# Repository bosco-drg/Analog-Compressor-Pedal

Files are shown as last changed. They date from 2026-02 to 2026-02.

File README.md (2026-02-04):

# Guitar Pedal — Analog Compressor

> Complete analog guitar compressor pedal project, including schematic and PCB design (KiCad) and simulations (LTSpice).

---

## Quick overview

This project designs and documents an **analog guitar compressor**: input/output adaptation, amplification, envelope detection, and gain control. It includes the **schematic**, **PCB**, as well as **simulations** and **test results**.

### Key features

- **Analog compression**: dynamic reduction of the audio signal
- **Complete signal chain**: input adaptation, amplification, peak detection, gain control, output adaptation
- **Hardware design**: schematic + PCB routing in KiCad
- **Simulation**: LTSpice models and sub‑block tests
- **Visual documentation**: block diagrams and simulation captures

---

## Circuit overview

<div align="center">

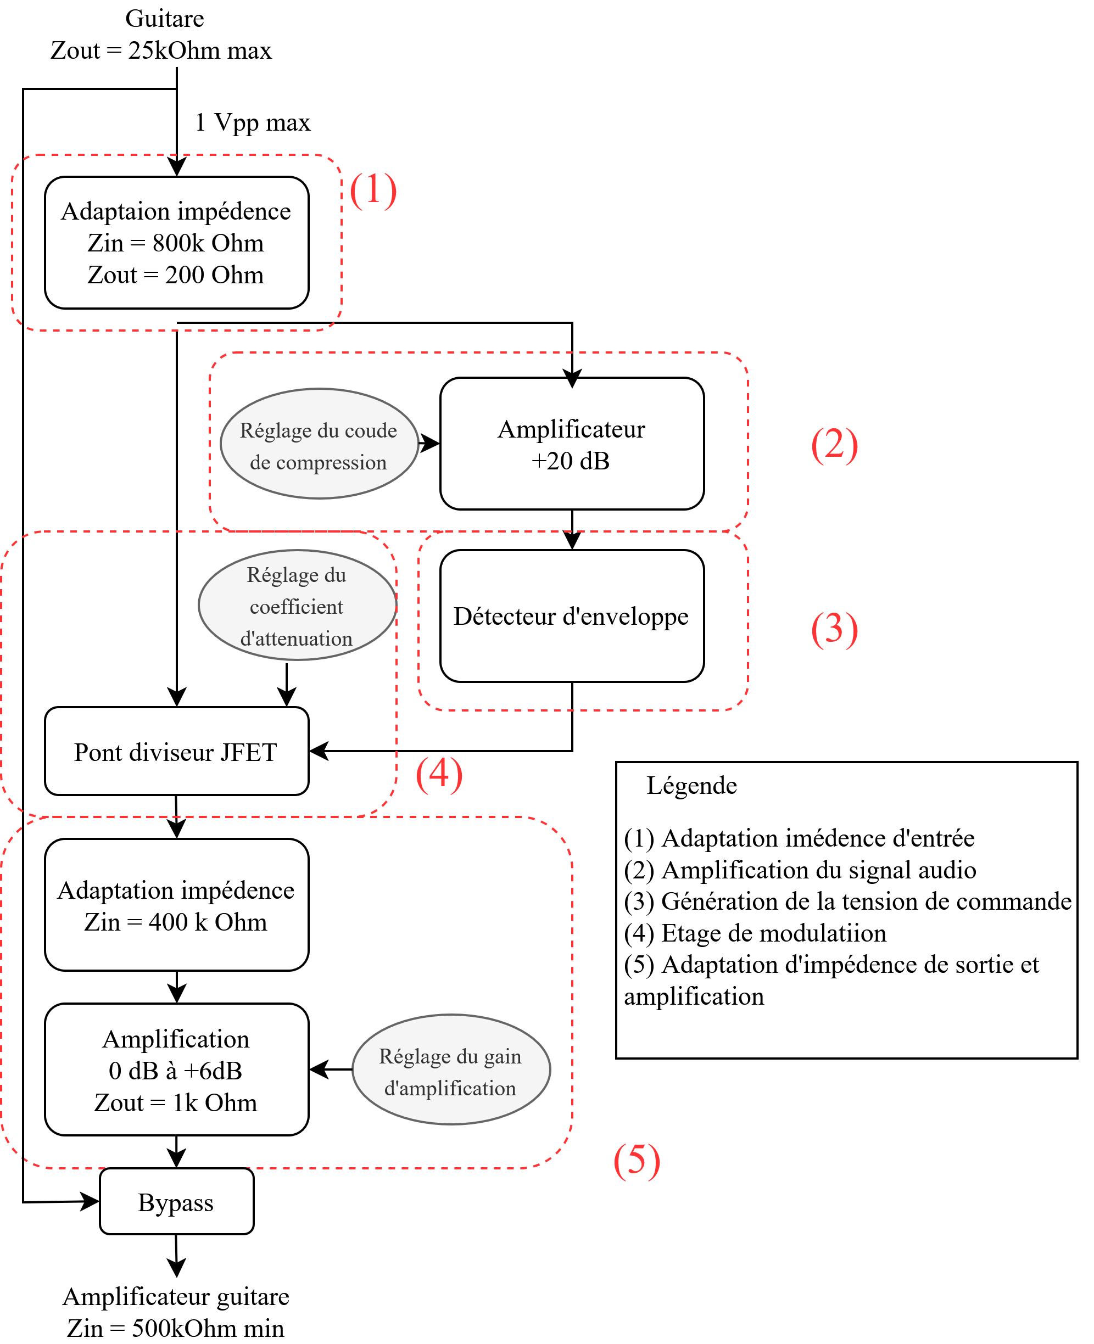
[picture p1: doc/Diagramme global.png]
Global diagram


**Global diagram** — *Functional architecture of the pedal*

</div>

<div align="center">

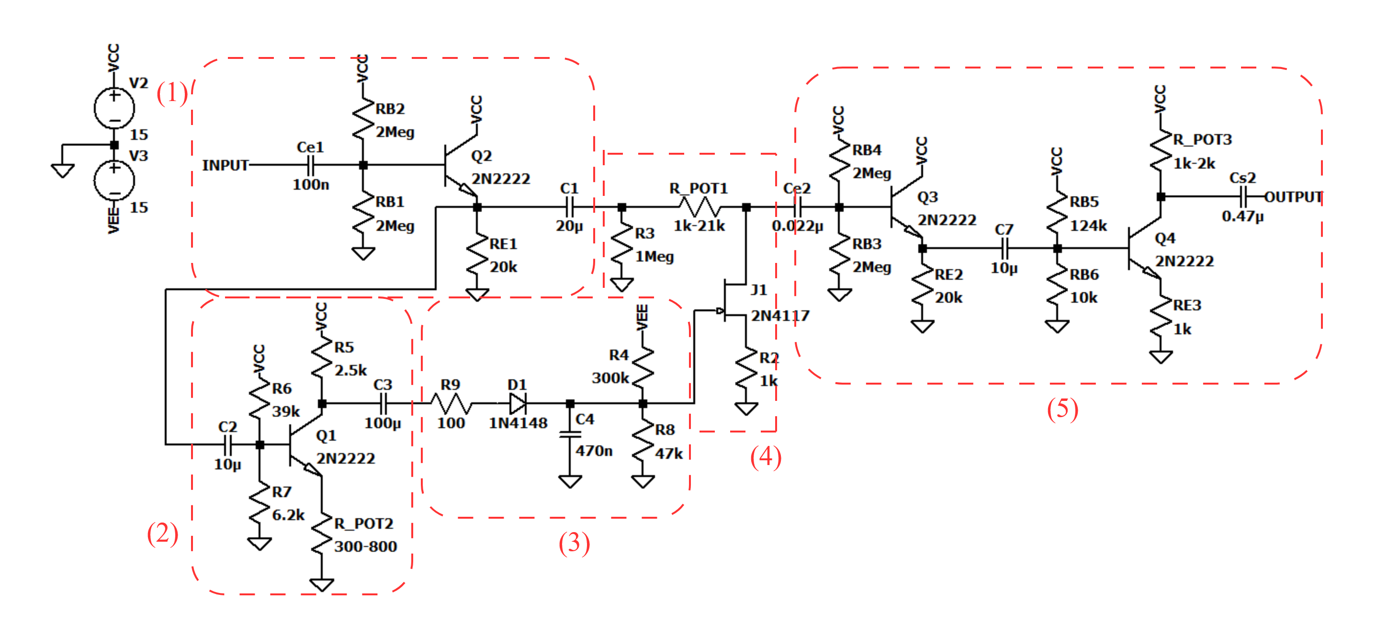
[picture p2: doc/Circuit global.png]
Global circuit


**Global circuit** — *Schematic overview*

</div>

---

## Sub‑block details

### Input adaptation

<div align="center">

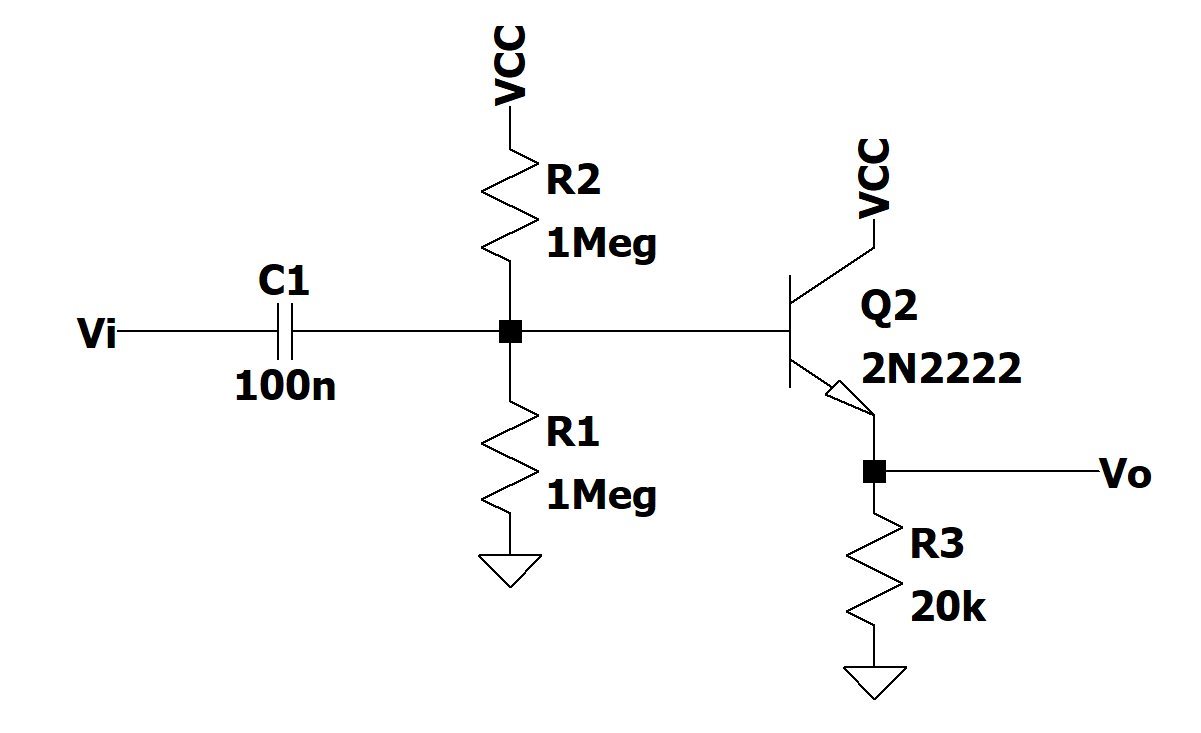
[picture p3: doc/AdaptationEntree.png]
Input adaptation


**Input adaptation** — *Guitar signal conditioning*

</div>

### Amplification

<div align="center">

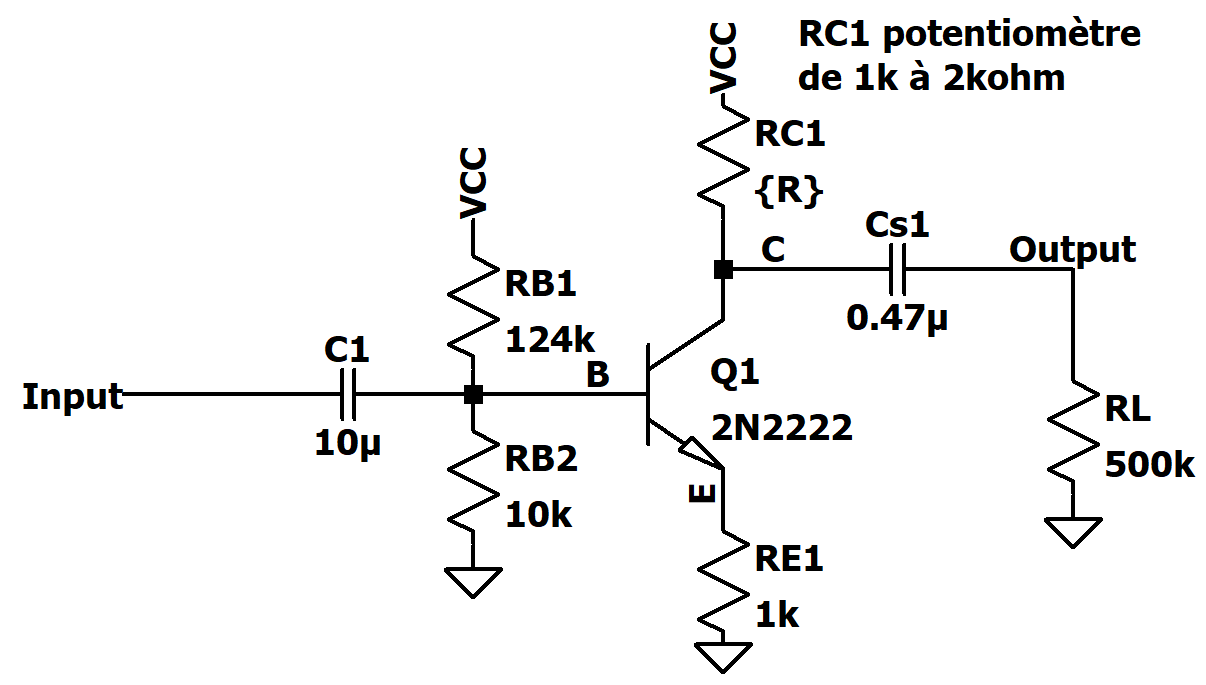
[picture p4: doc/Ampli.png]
Amplification


**Amplification** — *Signal amplification stages*

</div>

### Peak detection / envelope

<div align="center">

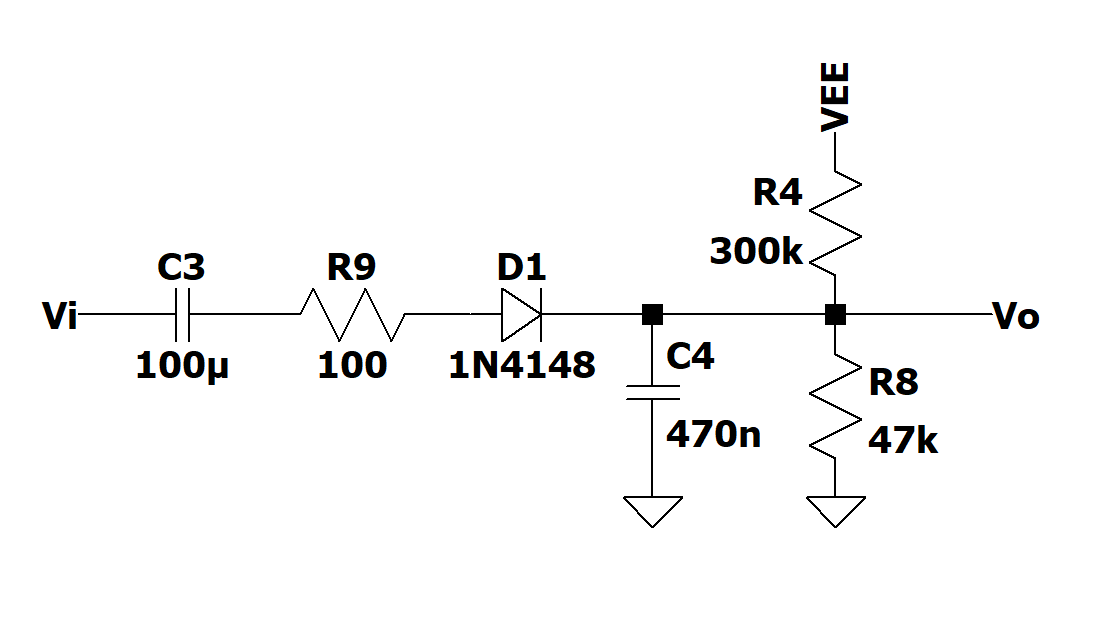
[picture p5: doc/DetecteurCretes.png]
Peak detection


**Peak detection** — *Envelope generation for control*

</div>

### Gain control / attenuation

<div align="center">

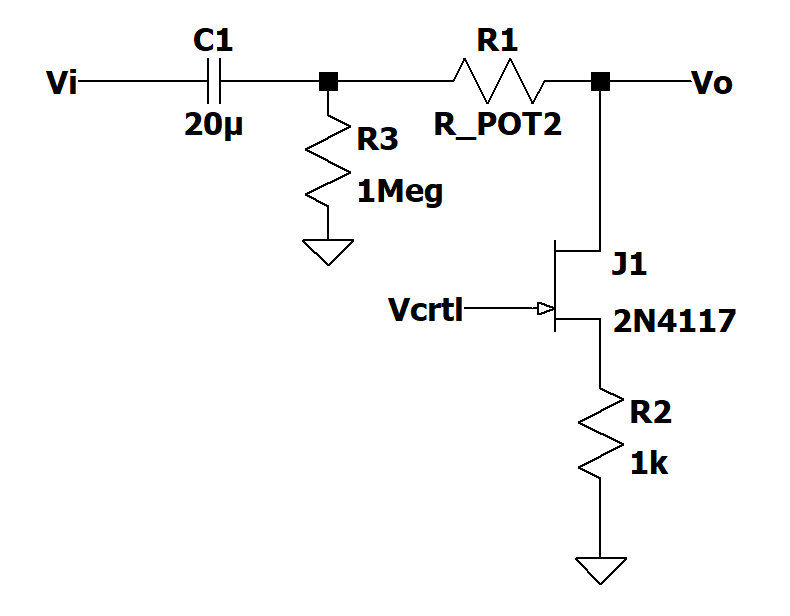
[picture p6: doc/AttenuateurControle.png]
Gain control


**Gain control** — *Envelope‑controlled attenuation*

</div>

### Output adaptation

<div align="center">

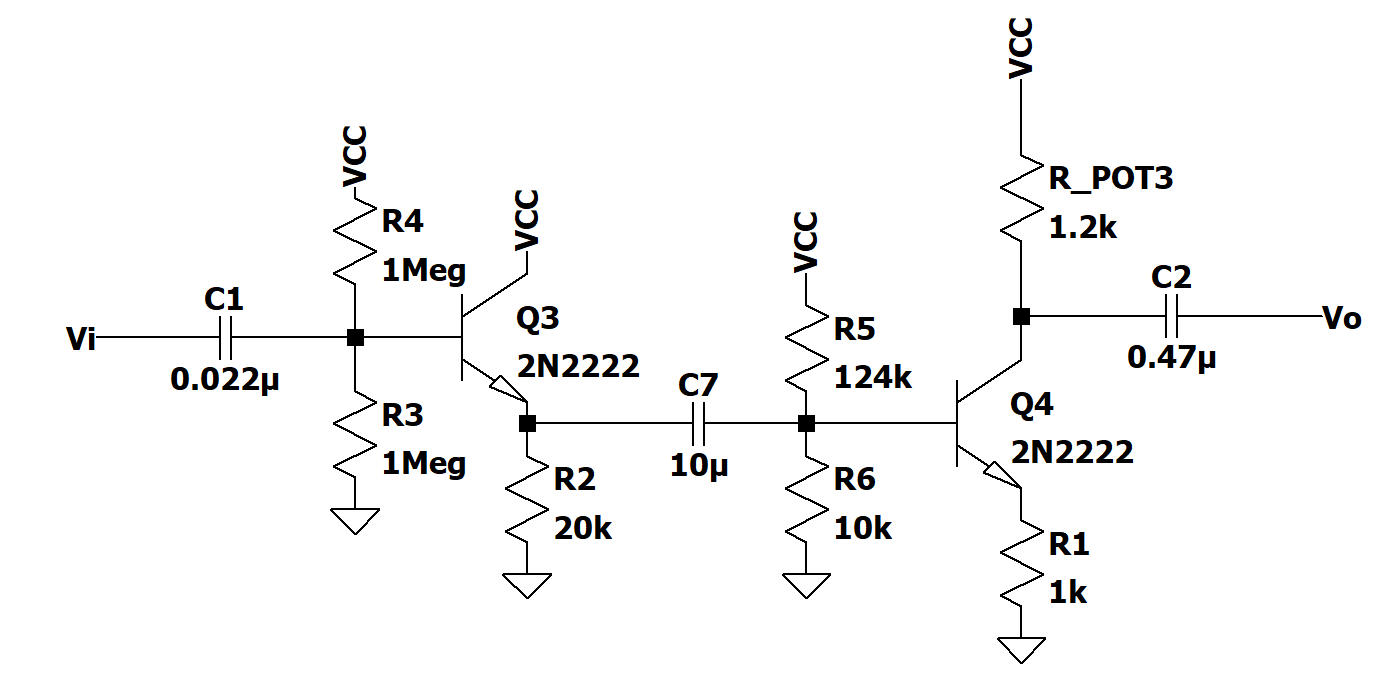
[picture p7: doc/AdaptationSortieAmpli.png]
Output adaptation


**Output adaptation** — *Compatibility with amp or audio interface*

</div>

---

## LTSpice simulations

<div align="center">

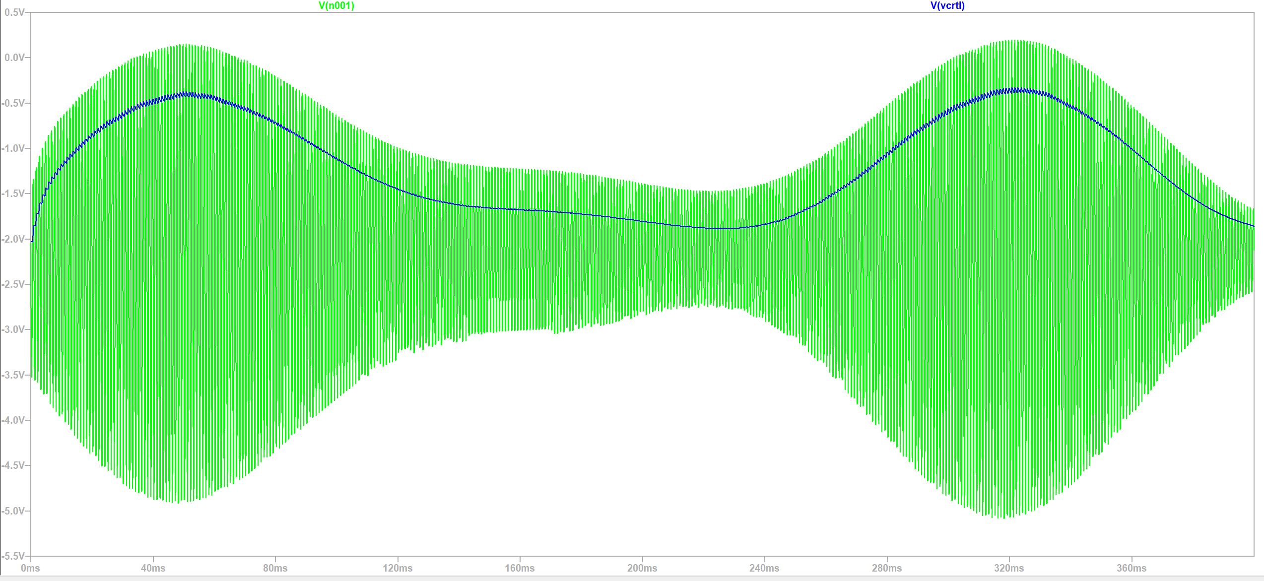
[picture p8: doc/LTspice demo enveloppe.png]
LTSpice envelope


**Envelope simulation** — *Detection response*

</div>

<div align="center">

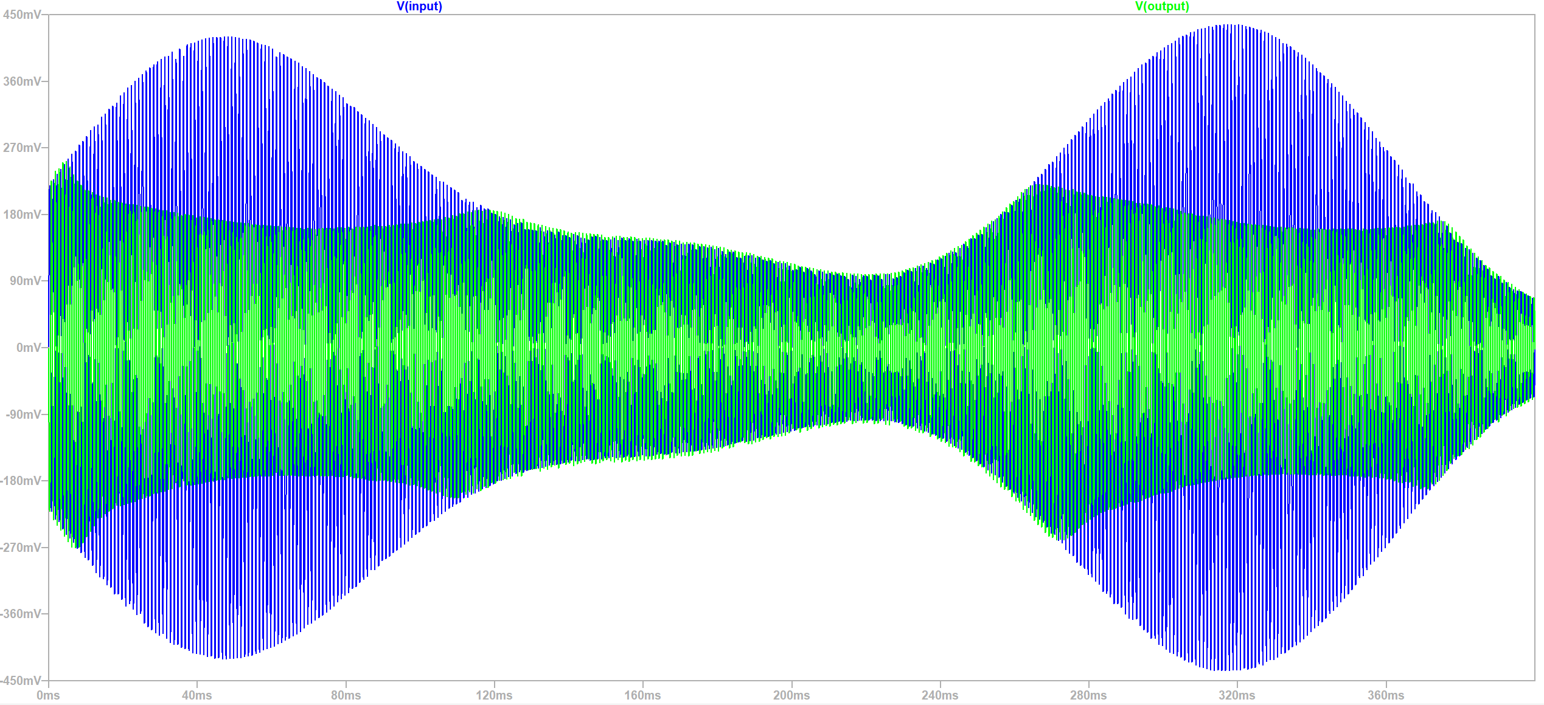
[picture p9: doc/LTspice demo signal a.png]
LTSpice signal


**Signal simulation** — *Compression effect on the signal*

</div>

---

## PCB — Photos

<div align="center">

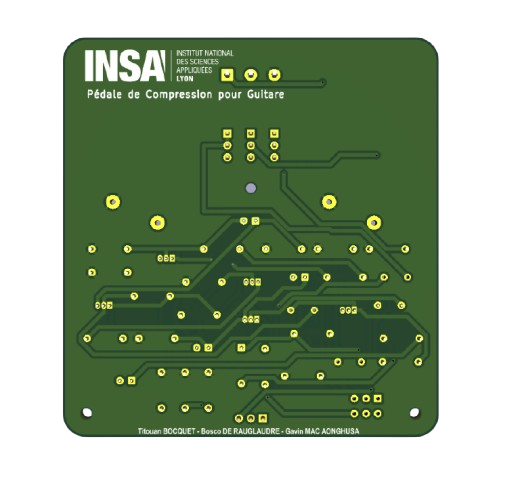
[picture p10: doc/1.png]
PCB back side


**PCB back side**

</div>

<div align="center">

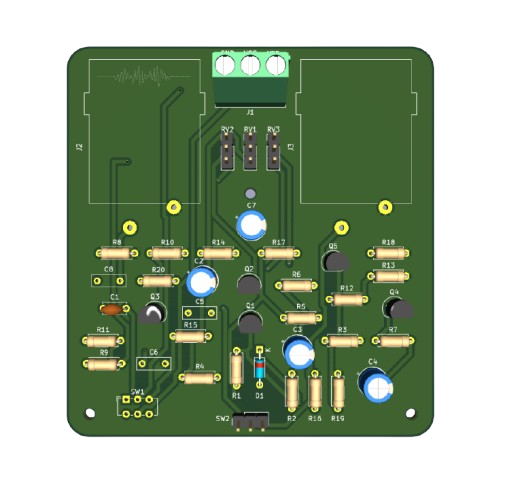
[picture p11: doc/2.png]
PCB component side


**PCB component side**

</div>

---

## Project structure

```
Analog-Compressor-Pedal/
├── README.md
├── doc/                       # Visual documentation and images
├── LTSpice/                   # Schematics and simulation tests
│   ├── Circuit_complet_avec_Adaptation.asc
│   ├── Audio Tests/
│   ├── Circuit Test Results/
│   └── PWL Sound Files/
└── pedaleGuitareComp/         # KiCad project (schematic + PCB)
		├── pedaleGuitareComp.kicad_sch
		├── pedaleGuitareComp.kicad_pcb
		└── footprints_perso/
```

---

## Open the project

### KiCad
- Open the project in [pedaleGuitareComp/](pedaleGuitareComp/)
- Main files:
	- Schematic: [pedaleGuitareComp/pedaleGuitareComp.kicad_sch](pedaleGuitareComp/pedaleGuitareComp.kicad_sch)
	- PCB: [pedaleGuitareComp/pedaleGuitareComp.kicad_pcb](pedaleGuitareComp/pedaleGuitareComp.kicad_pcb)

### LTSpice
- Full schematic: [LTSpice/Circuit_complet_avec_Adaptation.asc](LTSpice/Circuit_complet_avec_Adaptation.asc)
- Tests and results: [LTSpice/](LTSpice/)

---

## Authors

- **Bosco de Rauglaudre**
- **Titouan Bocquet**
- **Gavin Mac Aonghusa**

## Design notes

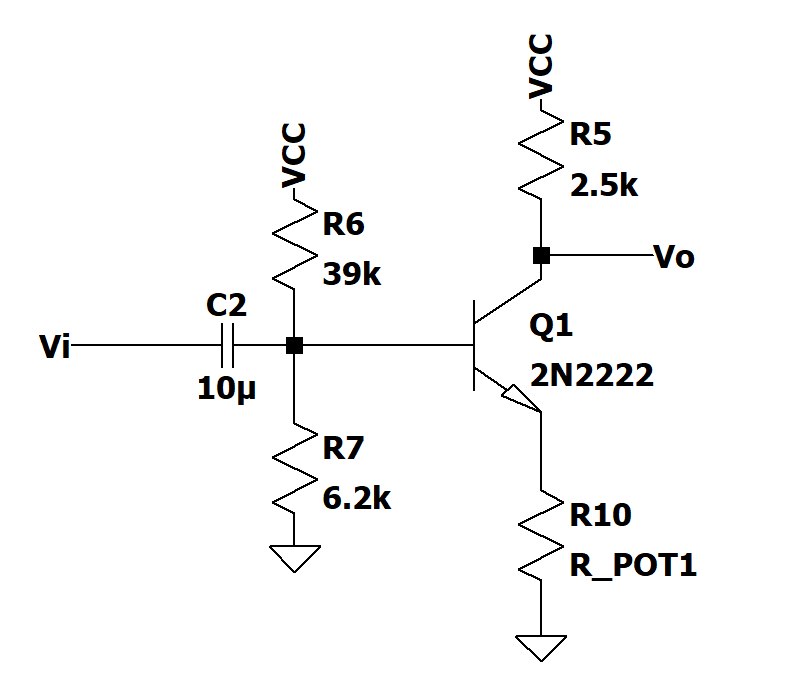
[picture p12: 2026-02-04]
doc/Ampli_INPUT.png

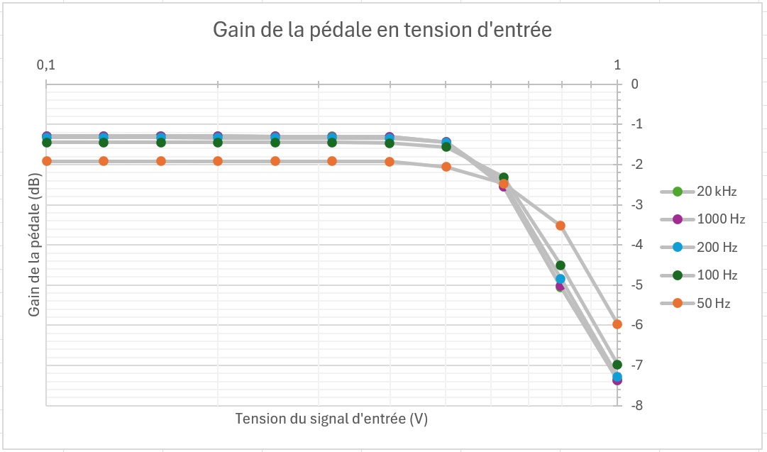
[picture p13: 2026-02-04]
doc/Baude gain.png

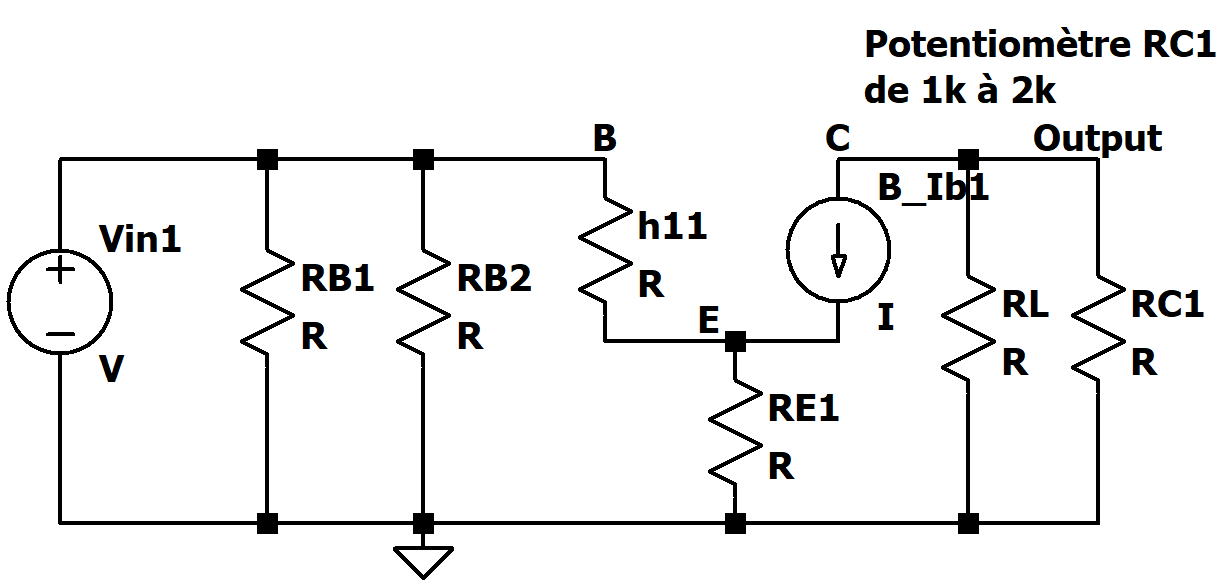
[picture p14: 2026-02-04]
doc/Ampli_petit_signaux.png

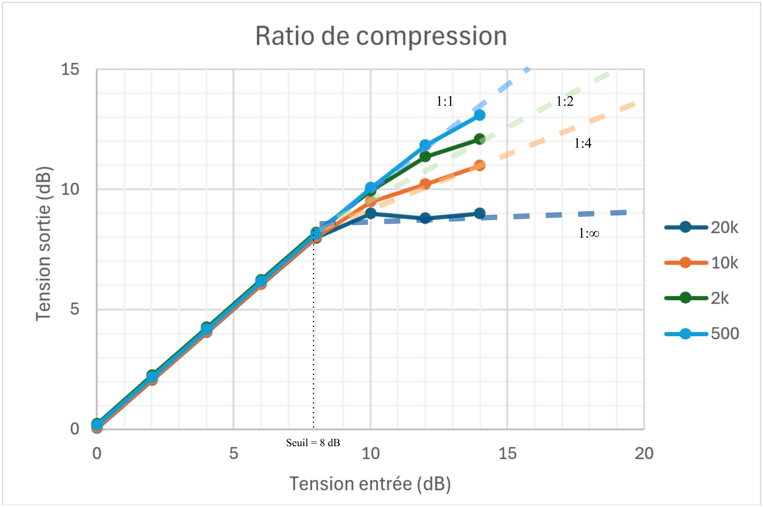
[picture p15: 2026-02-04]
doc/ratiocompression.png

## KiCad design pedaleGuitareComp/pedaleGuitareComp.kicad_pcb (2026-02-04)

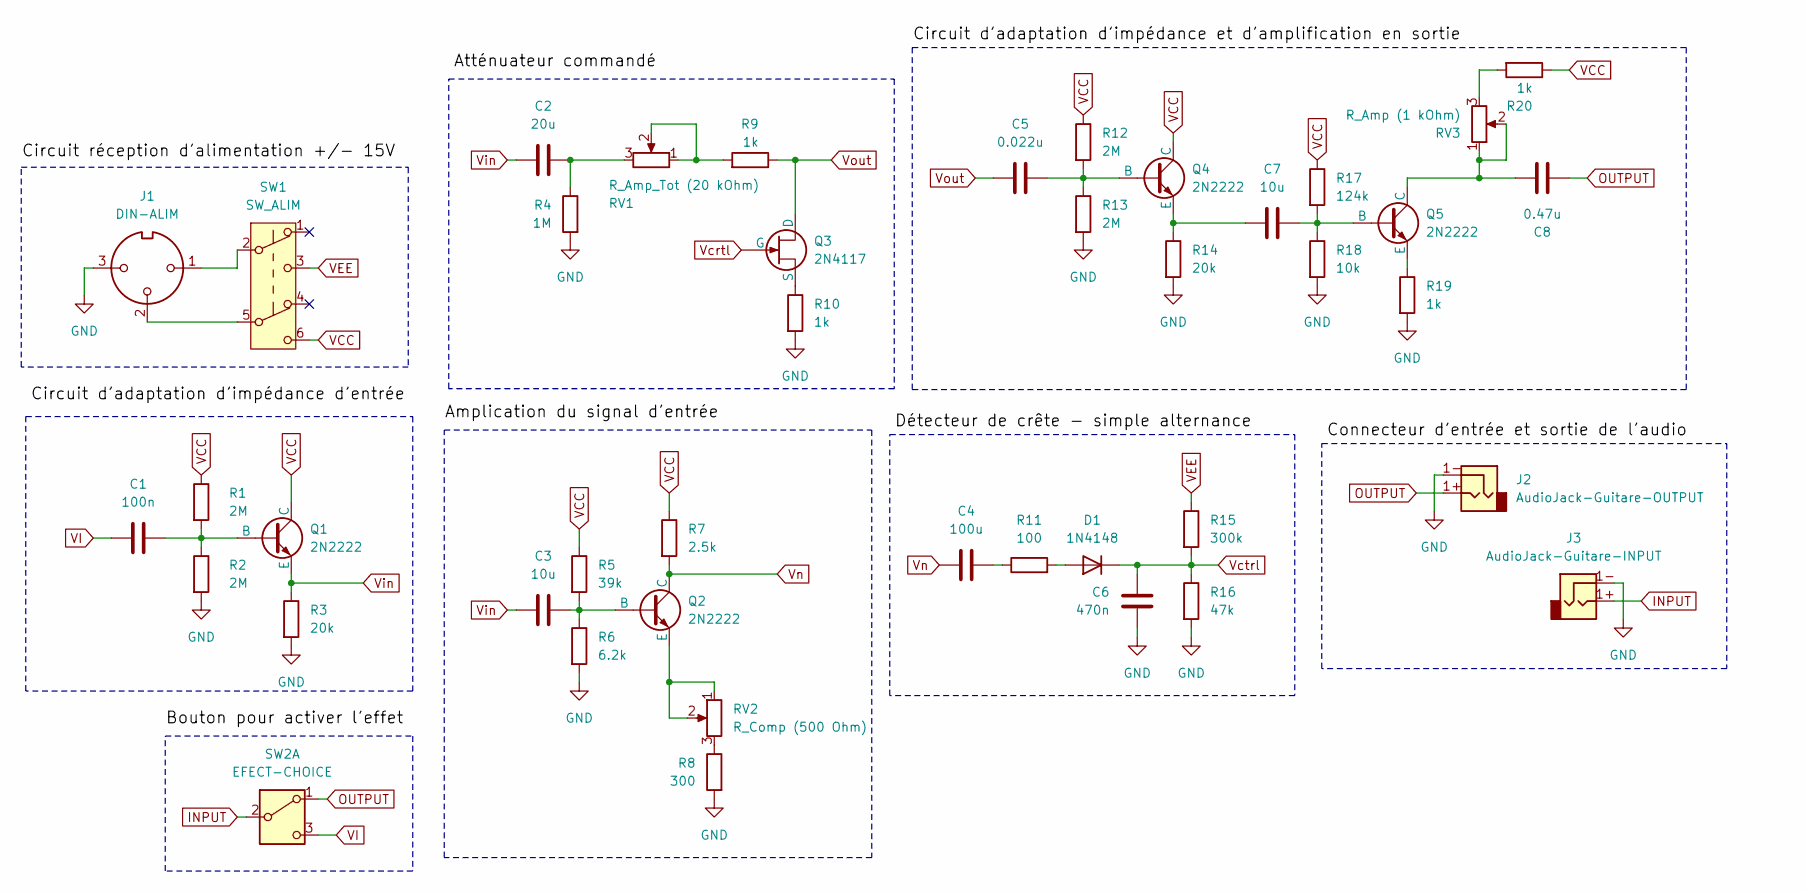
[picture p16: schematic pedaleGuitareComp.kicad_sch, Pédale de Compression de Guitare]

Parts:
C1: 100n; C_Disc_D5.0mm_W2.5mm_P5.00mm
C2: 20u; CP_Radial_D6.3mm_P2.50mm
C3, C7: 10u; CP_Radial_D6.3mm_P2.50mm
C4: 100u; CP_Radial_D6.3mm_P2.50mm
C5: 0.022u; C_Rect_L7.2mm_W2.5mm_P5.00mm
C6: 470n; C_Rect_L7.2mm_W2.5mm_P5.00mm
C8: 0.47u; C_Rect_L7.2mm_W2.5mm_P5.00mm
D1: 1N4148; D_DO-35_SOD27_P7.62mm_Horizontal
J1: DIN-ALIM; TerminalBlock_Phoenix_MKDS-1,5-3_1x03_P5.00mm_Horizontal
J2: AudioJack-Guitare-OUTPUT; Jack_speakON-6.35mm_Neutrik_NLJ2MDXX-H_Horizontal
J3: AudioJack-Guitare-INPUT; Jack_speakON-6.35mm_Neutrik_NLJ2MDXX-H_Horizontal
Q1, Q2, Q4, Q5: 2N2222; TO-92_Inline
Q3: 2N4117; TO-92_Inline
R1, R2, R12, R13: 2M; R_Axial_DIN0207_L6.3mm_D2.5mm_P7.62mm_Horizontal
R3, R14: 20k; R_Axial_DIN0207_L6.3mm_D2.5mm_P7.62mm_Horizontal
R4: 1M; R_Axial_DIN0207_L6.3mm_D2.5mm_P7.62mm_Horizontal
R5: 39k; R_Axial_DIN0207_L6.3mm_D2.5mm_P7.62mm_Horizontal
R6: 6.2k; R_Axial_DIN0207_L6.3mm_D2.5mm_P7.62mm_Horizontal
R7: 2.5k; R_Axial_DIN0207_L6.3mm_D2.5mm_P7.62mm_Horizontal
R8: 300; R_Axial_DIN0207_L6.3mm_D2.5mm_P7.62mm_Horizontal
R9, R10, R19, R20: 1k; R_Axial_DIN0207_L6.3mm_D2.5mm_P7.62mm_Horizontal
R11: 100; R_Axial_DIN0207_L6.3mm_D2.5mm_P7.62mm_Horizontal
R15: 300k; R_Axial_DIN0207_L6.3mm_D2.5mm_P7.62mm_Horizontal
R16: 47k; R_Axial_DIN0207_L6.3mm_D2.5mm_P7.62mm_Horizontal
R17: 124k; R_Axial_DIN0207_L6.3mm_D2.5mm_P7.62mm_Horizontal
R18: 10k; R_Axial_DIN0207_L6.3mm_D2.5mm_P7.62mm_Horizontal
RV1: R_Amp_Tot (20 kOhm); PinHeader_1x03_P2.54mm_Vertical
RV2: R_Comp (500 Ohm); PinHeader_1x03_P2.54mm_Vertical
RV3: R_Amp (1 kOhm); PinHeader_1x03_P2.54mm_Vertical
SW1: SW_ALIM; SW_E-Switch_EG1271_SPDT
SW2: EFECT-CHOICE; PinHeader_1x03_P2.54mm_Vertical

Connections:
GND: C6.2, J1.3, J2.1-, J3.1-, R2.2, R3.2, R4.2, R6.2, R8.2, R10.2, R13.2, R14.2, R16.2, R18.2, R19.2
INPUT: J3.1+, SW2.2 (B)
unnamed: C2.2, R4.1, RV1.3
unnamed: C4.1, R11.1
unnamed: D1.2 (A), R11.2
unnamed: J1.1, SW1.2 (B)
unnamed: J1.2, SW1.5 (B)
unnamed: C1.1, Q1.2 (B), R1.2, R2.1
unnamed: C3.2, Q2.2 (B), R5.2, R6.1
unnamed: Q2.3 (E), RV2.1, RV2.2
unnamed: Q3.3 (S), R10.1
unnamed: C5.1, Q4.2 (B), R12.2, R13.1
unnamed: C7.1, Q4.3 (E), R14.1
unnamed: C7.2, Q5.2 (B), R17.2, R18.1
unnamed: C8.1, Q5.1 (C), RV3.1, RV3.2
unnamed: Q5.3 (E), R19.1
unnamed: R8.1, RV2.3
unnamed: R9.2, RV1.1, RV1.2
unnamed: R20.2, RV3.3
OUTPUT: C8.2, J2.1+, SW2.1 (A)
VCC: Q1.1 (C), Q4.1 (C), R1.1, R5.1, R7.1, R12.1, R17.1, R20.1, SW1.6 (C)
VEE: R15.1, SW1.3 (C)
VI: C1.2, SW2.3 (C)
Vcrtl: Q3.2 (G)
Vctrl: C6.1, D1.1 (K), R15.2, R16.1
Vin: C2.1, C3.1, Q1.3 (E), R3.1
Vn: C4.2, Q2.1 (C), R7.2
Vout: C5.2, Q3.1 (D), R9.1

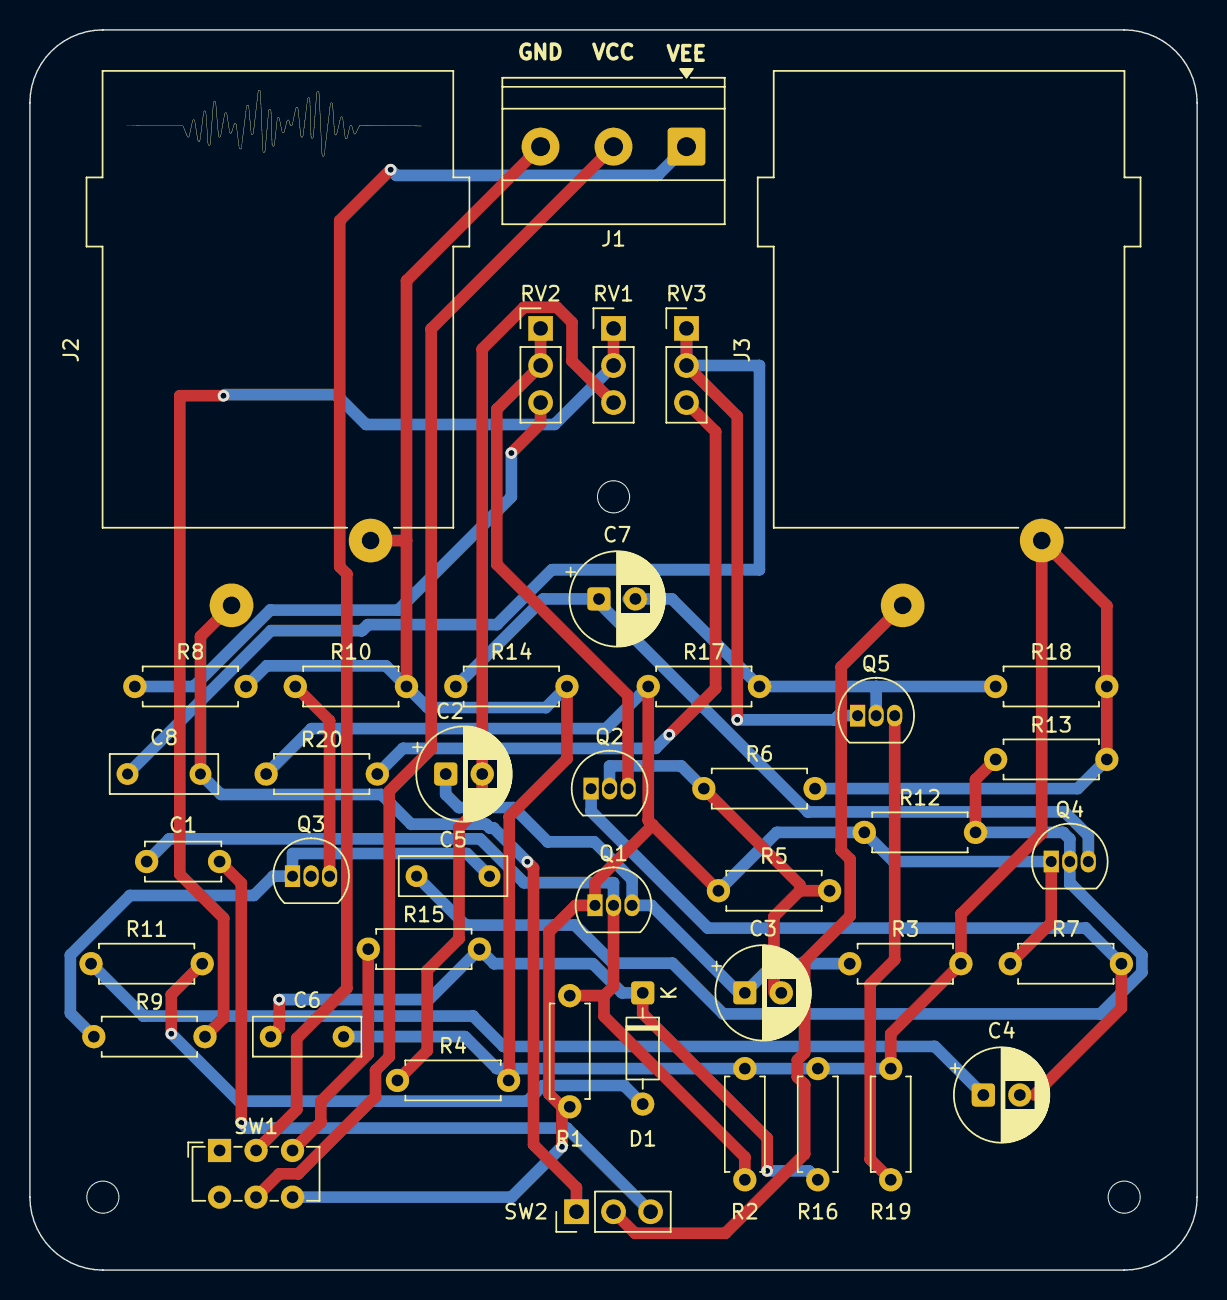
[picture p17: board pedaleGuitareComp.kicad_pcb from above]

Board: 2 copper layers, 80.0 x 85.0 mm, 42 parts (0 on the bottom side), 27 nets.

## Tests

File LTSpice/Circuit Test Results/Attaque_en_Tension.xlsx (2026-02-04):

 | Attaque
f(Hz) | Δt(ms)
100.00 | 12.65
500.00 | 14.60 | J'ai les capture d'écran s'ils sont nécessaire
1000.00 | 13.20
1500.00 | 13.70
3000.00 | 13.20
5000.00 | 16.60 | Vpp/2
10000.00 | 14.10 |  | Attaque
15000.00 | 13.20 | V_peak(V) | Δt(ms)
20000.00 | 14.10 | 0.30 | 14.00
 | 13.93 | 0.35 | 13.70
 |  | 0.40 | 12.20
 |  | 0.45 | 12.20
 |  | 0.50 | 14.00
 |  | moyenne | 13.22

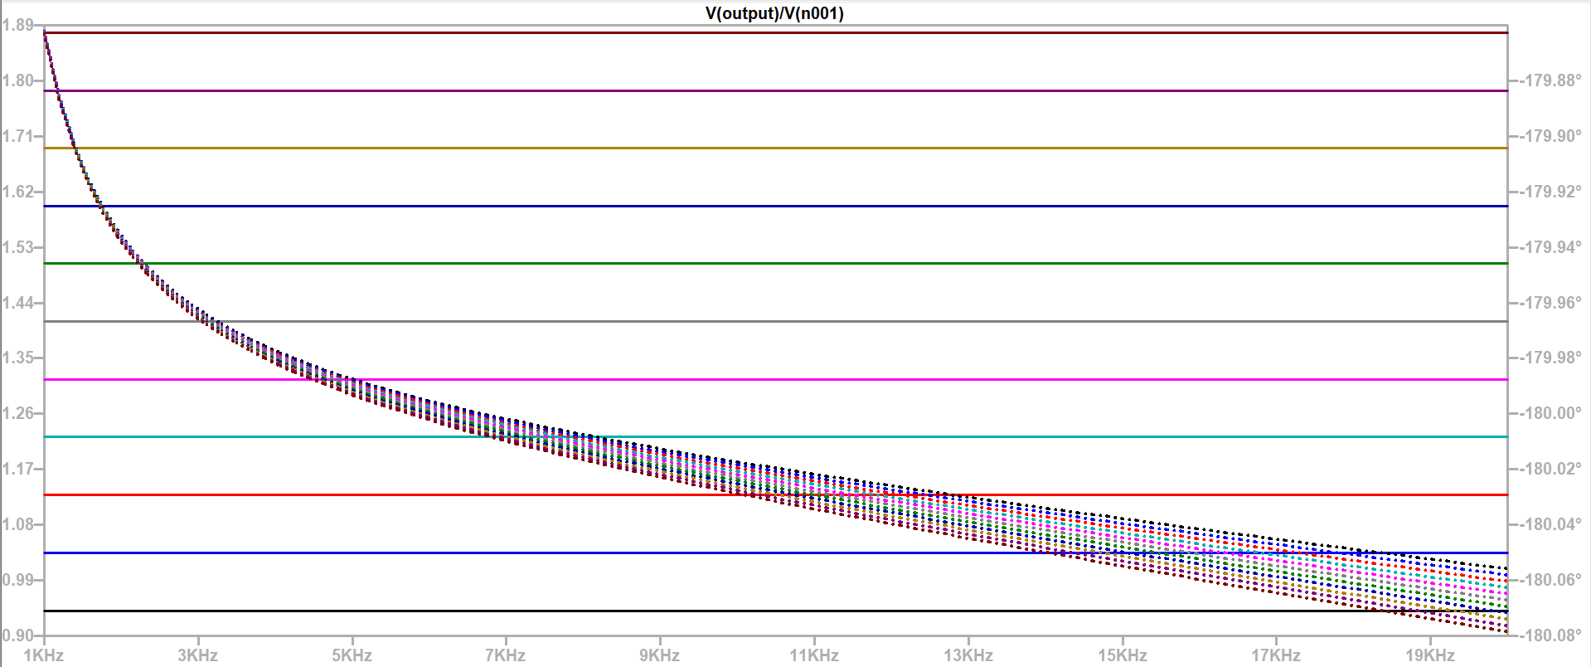
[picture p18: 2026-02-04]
doc/AdaptationEntree_Test.png

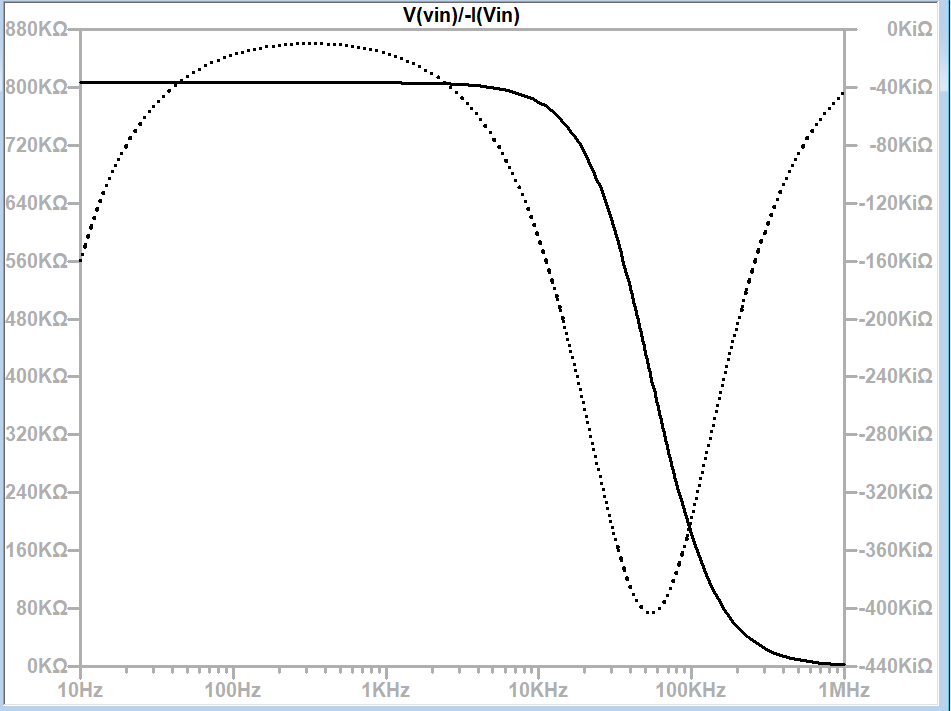
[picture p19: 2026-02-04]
doc/Ampli_Test.png
